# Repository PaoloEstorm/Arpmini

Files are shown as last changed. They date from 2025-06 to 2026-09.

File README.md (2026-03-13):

# ARPMINI

Arpmini is a powerful mini MIDI processor that offers advanced features such as an arpeggiator, note/drum sequencer, and editor. It’s designed to control external MIDI instruments for live performances or music production.

# ARPMINI REQUIRES [Arpmini-Core](https://github.com/PaoloEstorm/Arpmini-Core) TO WORK CORRECTLY!

## Give that dusty old synth in your closet a fresh new life! Unlock a ton of advanced features and unleash your creativity with Arpmini



## Its features include:

Simple and intuitive UI

MIDI Tracker and Piano Roll–style sequence editors

Four backlit buttons, mappable and controllable via MIDI CC

2 MIDI outputs and 2 MIDI inputs - using the MIDI-TRS standard

Integrated MIDI->USB / USB->MIDI interface, fully compatible with Mac, Windows, Linux, Android and iOS 

32KB of memory to store up to 60 songs and various global settings

Import/export songs between Arpmini and your computer using [Arpmini Editor](https://github.com/PaoloEstorm/Arpmini-Editor)

Built-in speaker for acoustic feedback and metronome and much much more!

## Arpmini Modes

Modes

Arp Mode: Arpeggiates the played notes based on the selected arpeggio style.

Rec Mode: Records and plays back up to 8 patterns of variable length, with a maximum of 32 notes each.

Song Mode: Allows to chain up 8 recorded patterns, in any desired order.

Live Mode: Allows the playback of one of the 8 different patterns, each assigned to one buttons/multi-button-combo.

Wiring

A simulated demo of Arpmini can be explored on Wokwi via the link https://wokwi.com/projects/430279970010982401

Simplified Schematic:

Schematic_DIY

# Build your own Arpmini by following the [Assembly Guide](https://github.com/PaoloEstorm/Arpmini/blob/main/BUILD_INSTRUCTIONS.md)!

## Schematic and PCB design [here](https://oshwlab.com/estorm/miniseq)

Enclosure 3D model [here](https://github.com/PaoloEstorm/Arpmini/blob/main/extras/Arpmini%201.65%20v3.stl)

Pro Micro: https://amzn.eu/d/if0r67j

Oled Display (blue): https://amzn.eu/d/c0RTBxJ or Oled Display (white): https://amzn.eu/d/1IbVAiL

Buttons: https://amzn.eu/d/7UyjFKx

Buzzer: https://amzn.eu/d/fEAc4UO

Screws: https://amzn.eu/d/e37jcLp

Brass inserts: https://amzn.eu/d/hlBMRaH

Pin Headers: https://amzn.eu/d/9up7Byu

3.5mm Stereo jacks: https://amzn.eu/d/9LeCoT1

External labels [here](https://github.com/PaoloEstorm/Arpmini/tree/main/extras)

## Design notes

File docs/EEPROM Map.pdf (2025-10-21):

System | 0 - MIDI Channel | 1 - Realtime | 2 - Sound Mode | 3 - Sync Port | 4 - Red CC | 5 - Yellow CC | 6 - Blue CC | 7 - Green CC | 8 – Empty | 9 – Empty | 10 – Empty | 11 – Empty | 12 – Empty | 13 – Empty | 14 – Empty | 15 – Check
| 16 –Empty | 17 – Empty | 18 – Empty | 19 – Empty | 20 – Empty | 21 – Empty | 22 – Empty | 23 – Empty | 24 – Empty | 25 – Empty | 26 – Empty | 27 – Empty | 28 – Empty | 29 – Empty | 30 – Empty | 31 – Empty
Song1 | 32 - Empty/Full | 33
| | Pitch-Mode+Swing | 34 – Pitch | 35 – Scale | 36– Post-Transpose | 37 - Seq. Length | 38 - BPM | 39 – Speed | 40 - Pattern 1 | 41 - Pattern 2 | 42 - Pattern 3 | 43 - Pattern 4 | 44 - Pattern 5 | 45 - Pattern 6 | 46 - Pattern 7 | 47 - Pattern 8
Sequence 1 | 48 | 49 | 50 | 51 | 52 | 53 | 54 | 55 | 56 | 57 | 58 | 59 | 60 | 61 | 62 | 63
| 64 | 65 | 66 | 67 | 68 | 69 | 70 | 71 | 72 | 73 | 74 | 75 | 76 | 77 | 78 | 79
Sequence 2 | 80 | 81 | 82 | 83 | 84 | 85 | 86 | 87 | 88 | 89 | 90 | 91 | 92 | 93 | 94 | 95
| 96 | 97 | 98 | 99 | 100 | 101 | 102 | 103 | 104 | 105 | 106 | 107 | 108 | 109 | 110 | 111
Sequence 3 | 112 | 113 | 114 | 115 | 116 | 117 | 118 | 119 | 120 | 121 | 122 | 123 | 124 | 125 | 126 | 127
| 128 | 129 | 130 | 131 | 132 | 133 | 134 | 135 | 136 | 137 | 138 | 139 | 140 | 141 | 142 | 143
Sequence 4 | 144 | 145 | 146 | 147 | 148 | 149 | 150 | 151 | 152 | 153 | 154 | 155 | 156 | 157 | 158 | 159
| 160 | 161 | 162 | 163 | 164 | 165 | 166 | 167 | 168 | 169 | 170 | 171 | 172 | 173 | 174 | 175
Sequence 5 | 176 | 177 | 178 | 179 | 180 | 181 | 182 | 183 | 184 | 185 | 186 | 187 | 188 | 189 | 190 | 191
| 192 | 193 | 194 | 195 | 196 | 197 | 198 | 199 | 200 | 201 | 202 | 203 | 204 | 205 | 206 | 207
Sequence 6 | 208 | 209 | 210 | 211 | 212 | 213 | 214 | 215 | 216 | 217 | 218 | 219 | 220 | 221 | 222 | 223
| 224 | 225 | 226 | 227 | 228 | 229 | 230 | 231 | 232 | 233 | 234 | 235 | 236 | 237 | 238 | 239
Sequence 7 | 240 | 241 | 242 | 243 | 244 | 245 | 246 | 247 | 248 | 249 | 250 | 251 | 252 | 253 | 254 | 255
| 256 | 257 | 258 | 259 | 260 | 261 | 262 | 263 | 264 | 265 | 266 | 267 | 268 | 269 | 270 | 271
Sequence 8 | 272 | 273 | 274 | 275 | 276 | 277 | 278 | 279 | 280 | 281 | 282 | 283 | 284 | 285 | 286 | 287
| 288 | 289 | 290 | 291 | 292 | 293 | 294 | 295 | 296 | 297 | 298 | 299 | 300 | 301 | 302 | 303

Drum notes /
Shifts | 304 | 305 | 306 | 307 | 308 | 309 | 310 | 311 | 312 – Empty | 313 - Empty | 314 – Empty | 315 – Empty | 316 – Empty | 317 – Empty | 318 – Empty | 319 – Empty
Song2 | 320 | … | … | … | … | … | … | … | … | … | … | … | … | … | … | …

# EEPROM MAP (EXTERNAL)

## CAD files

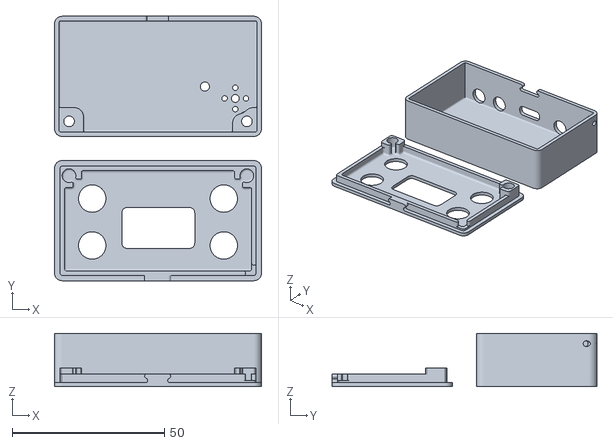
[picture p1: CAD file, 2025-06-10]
extras/Arpmini 1.65 v3.stl
68.0 x 86.9 x 17.5

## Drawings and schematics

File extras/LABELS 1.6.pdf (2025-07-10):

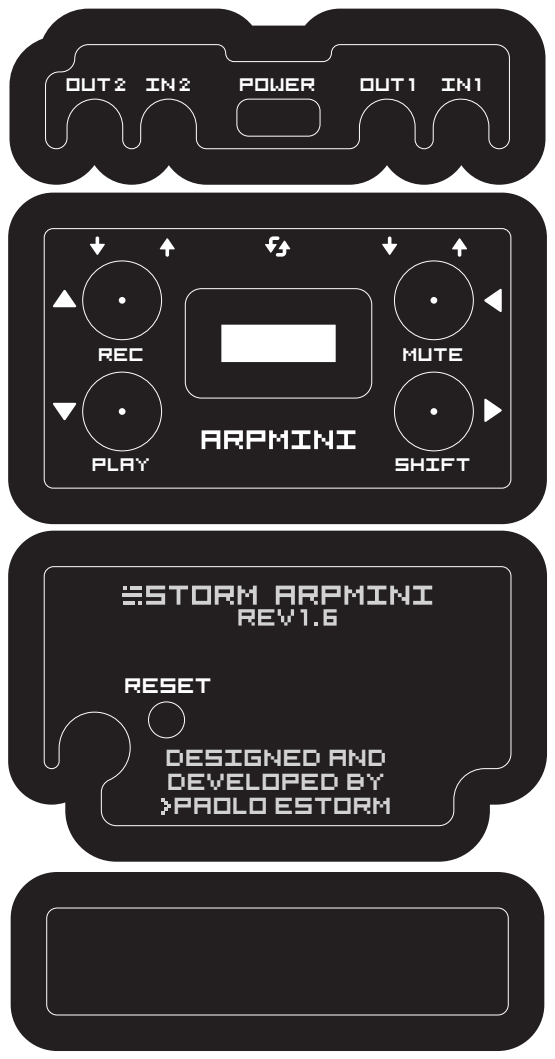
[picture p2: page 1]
OUT 2; POWER; OUT 1; DESIGNED AND DEVELOPED BY PAOLO ESTORM; RESET; REC; PLAY; MUTE; SHIFT

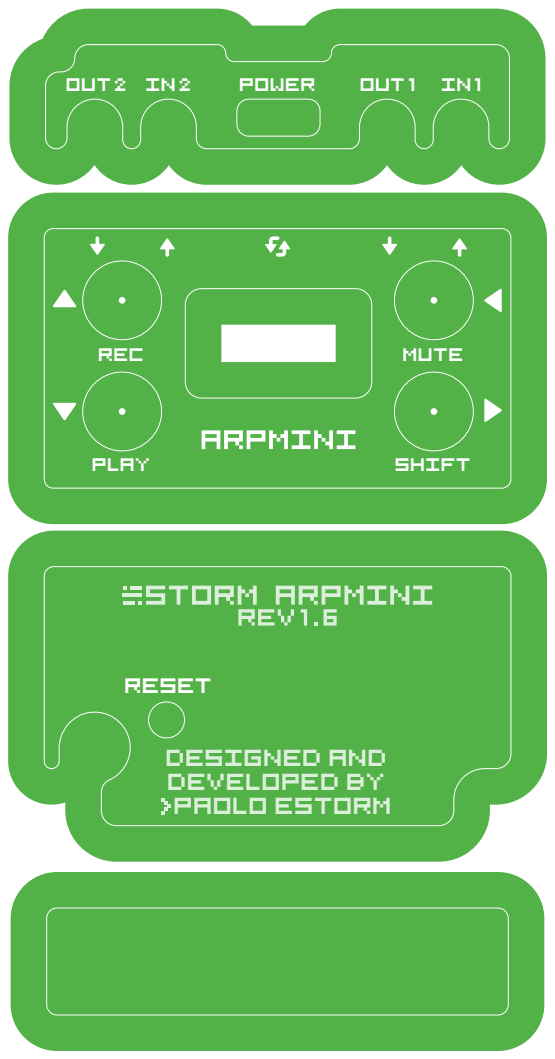
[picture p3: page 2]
OUT 2; POWER; OUT 1; DESIGNED AND DEVELOPED BY PAOLO ESTORM; RESET; REC; PLAY; MUTE; SHIFT

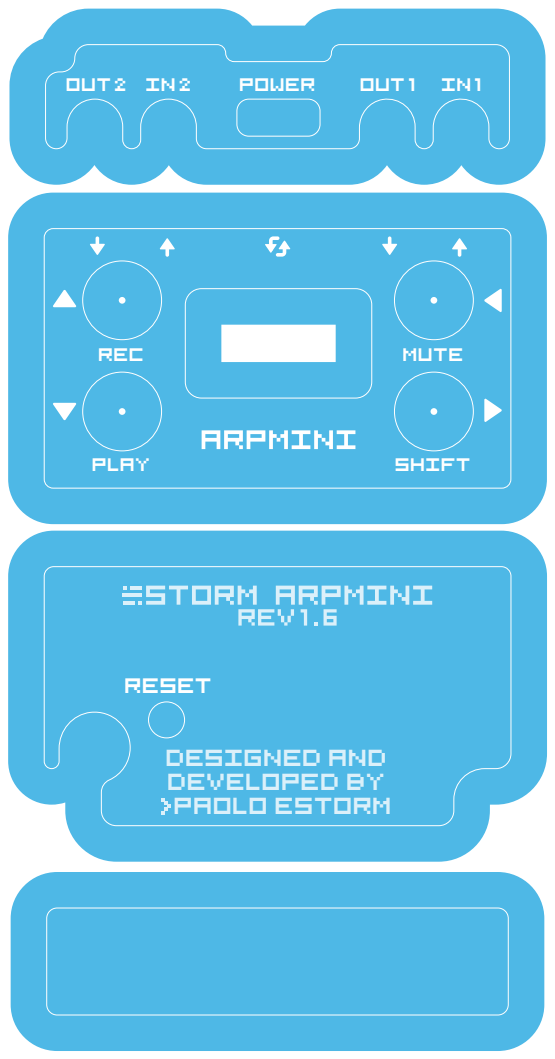
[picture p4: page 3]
OUT 2; POWER; OUT 1; DESIGNED AND DEVELOPED BY PAOLO ESTORM; RESET; REC; PLAY; MUTE; SHIFT

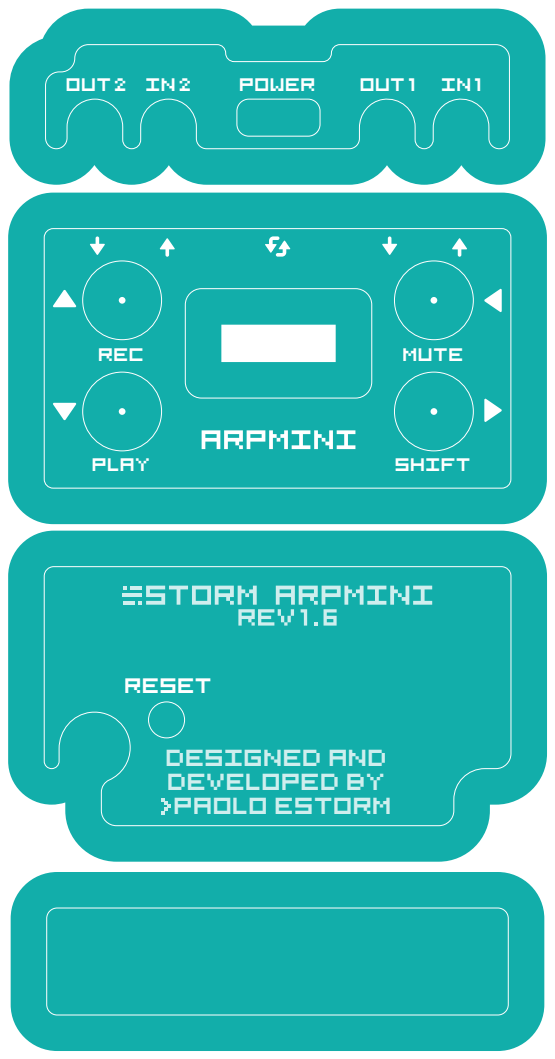
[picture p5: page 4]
OUT 2; POWER; OUT 1; DESIGNED AND DEVELOPED BY PAOLO ESTORM; RESET; REC; PLAY; MUTE; SHIFT

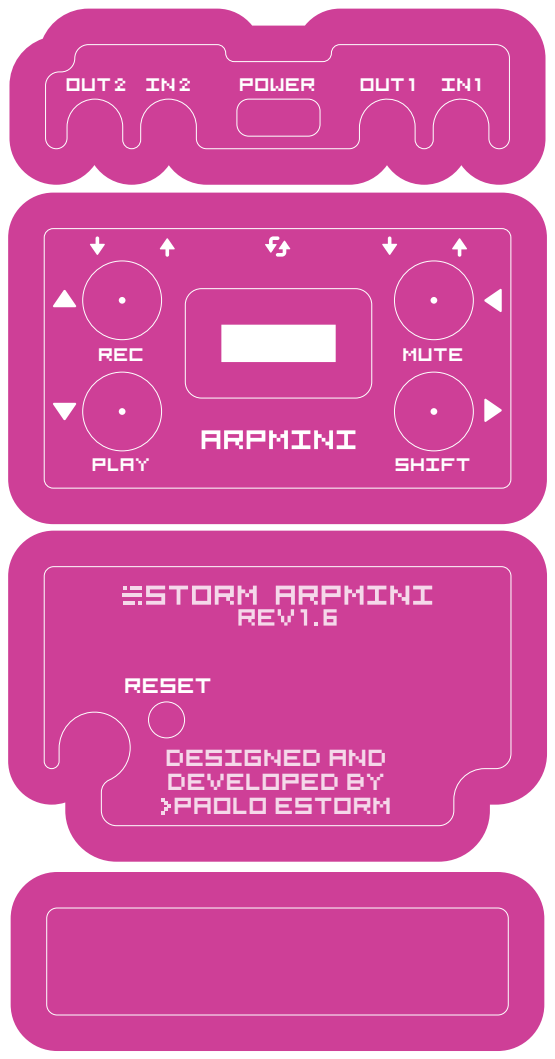
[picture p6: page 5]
OUT 2; POWER; OUT 1; DESIGNED AND DEVELOPED BY PAOLO ESTORM; RESET; REC; PLAY; MUTE; SHIFT

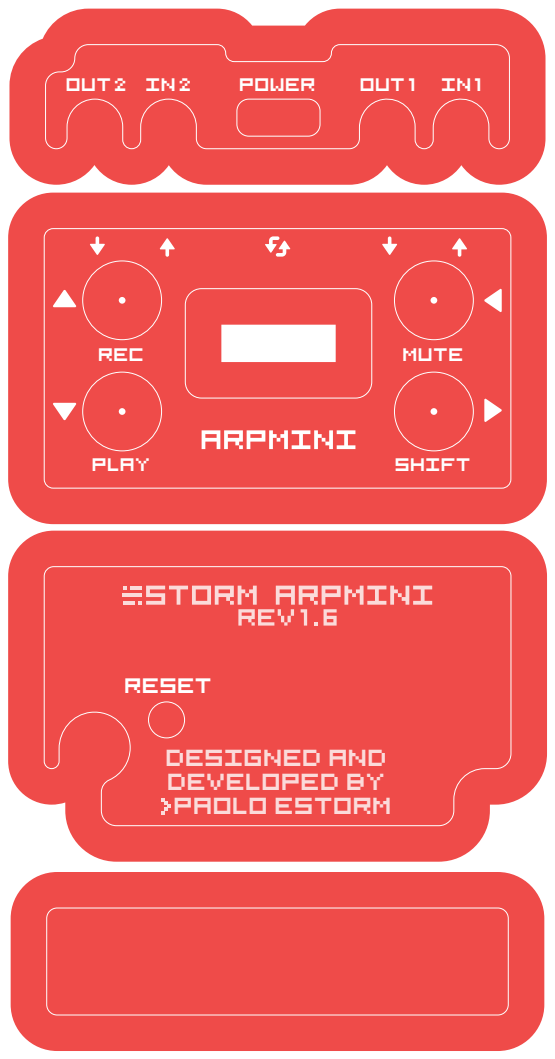
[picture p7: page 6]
OUT 2; POWER; OUT 1; DESIGNED AND DEVELOPED BY PAOLO ESTORM; RESET; REC; PLAY; MUTE; SHIFT

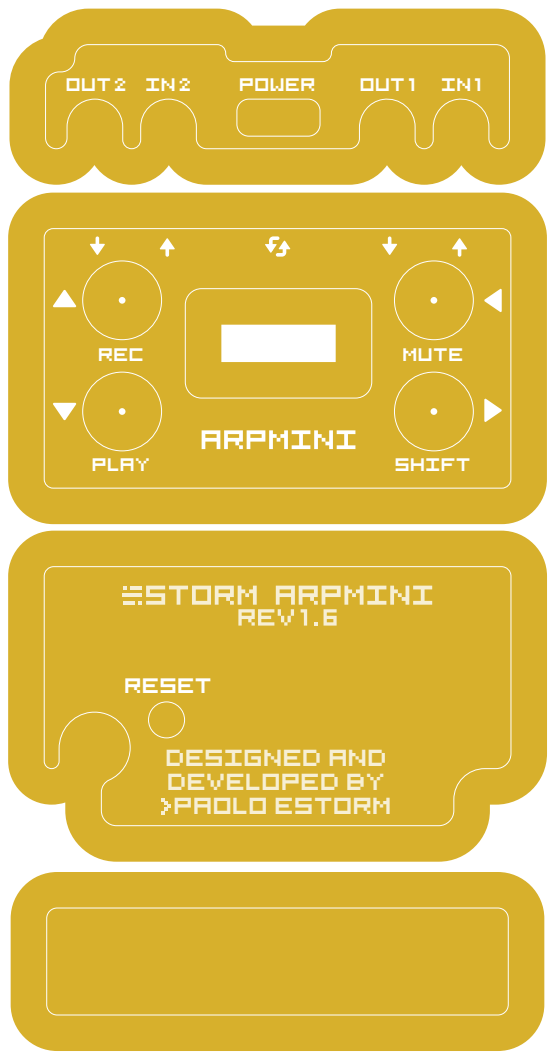
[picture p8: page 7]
OUT 2; POWER; OUT 1; DESIGNED AND DEVELOPED BY PAOLO ESTORM; RESET; REC; PLAY; MUTE; SHIFT

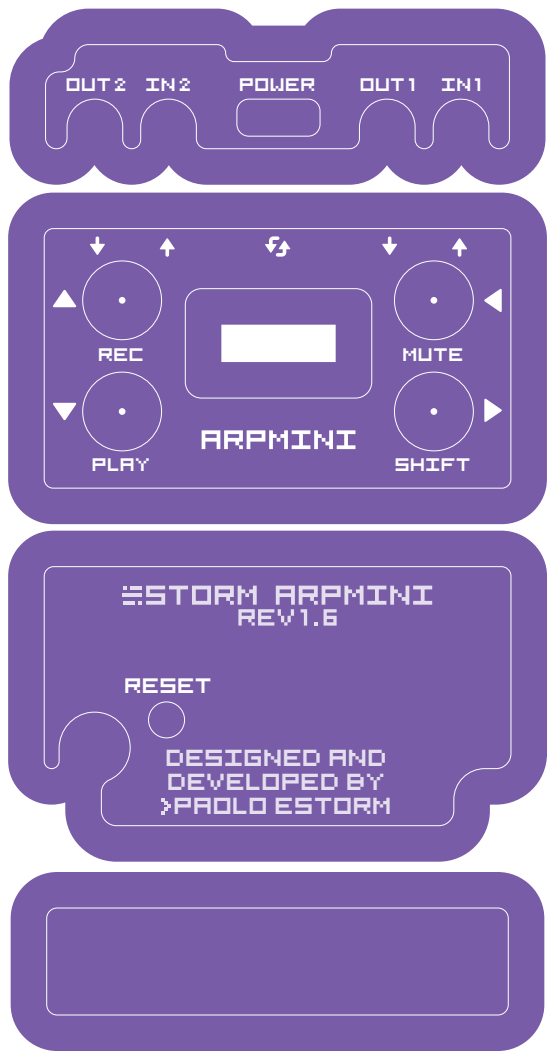
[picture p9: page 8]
OUT 2; POWER; OUT 1; DESIGNED AND DEVELOPED BY PAOLO ESTORM; RESET; REC; PLAY; MUTE; SHIFT

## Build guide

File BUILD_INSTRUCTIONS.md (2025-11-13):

# Arpmini Assembly Guide



Required components: 
- 1x Pro Micro: https://amzn.eu/d/if0r67j
- 1x Arpmini PCBs: https://oshwlab.com/estorm/miniseq
- 1x 0,96" SPI Oled Display (Blue): https://amzn.eu/d/c0RTBxJ or (White): https://amzn.eu/d/1IbVAiL
- 4x Button+LED, (1x Red, 1x Yellow, 1x Green, 1x Blue): https://amzn.eu/d/7UyjFKx
- 1x 9x5.5mm Buzzer: https://amzn.eu/d/fEAc4UO
- 2x M3-14mm Screws: https://amzn.eu/d/e37jcLp
- 2x Brass Inserts: https://amzn.eu/d/hlBMRaH
- 4x 3.5mm Stereo Jacks: https://amzn.eu/d/9LeCoT1
- 1x Single Row Male Pin Header Strip: https://amzn.eu/d/9up7Byu
- 1x 3D Printed Enclosure: https://github.com/PaoloEstorm/Arpmini/blob/main/extras/Arpmini%201.65%20v3.stl
- Optional, External Labels: https://github.com/PaoloEstorm/Arpmini/tree/main/extras

## Some parts will no longer be easily accessible after assembly, so make sure you have everything you need before starting, and follow the steps in the exact order.




Insert the four 3.5 mm jack sockets into their corresponding holes, making sure to mount them on the correct side of the PCB; the one with the logo and SMD components.



While keeping the sockets in place, solder each exposed pin one by one, making sure the connectors stay as straight, flat, and aligned with the PCB as possible.
You can use a strip of adhesive tape to hold them steady during the process if needed.



Using a flush side cutter, trim the excess length of the soldered pins as much as possible.
Be careful not to damage the PCB traces; a clean trim helps prevent short circuits in later assembly steps.



Take the Pro Micro board and make sure you have the male pin headers ready.
They usually come included with the board. If not, cut two 12-pin strips from a longer header.



Most Pro Micro boards include two small pads located next to the TX pin. These pads define the board’s operating voltage:
if the pads are not bridged, the board runs at 3.3V;
if they are bridged, the board runs at 5V.



Arpmini operates at 5V, so the pads MUST be bridged using a small amount of solder.
Be careful not to damage nearby components. A fine-tip soldering iron and moderate temperature (around 280°C / 536°F) make the process easy.



Insert the two 12-pin male headers into the holes, making sure to place them on the side of the PCB with the "Pro Micro" label and the microcontroller.
Flip the board and solder all pins, aiming for clean joints without using too much solder, while keeping the headers pressed firmly against the board.
Using a breadboard to hold the pins in place during soldering can be very helpful!



Once the headers are soldered, proceed to flash the bootloader specifically designed for Arpmini.
To connect the board to the ISP, it is recommended to use Dupont jumper cables to avoid soldering.

Alternatively, you can temporarily solder wires on the back side of the board, where the headers were just soldered, while keeping the front headers untouched.

Bootloader_ProMicro_Wiring

Follow the instructions available [here](https://github.com/PaoloEstorm/Arpmini-Core) to install the Arpmini Core in the Arduino IDE.
Once installed, go to Tools -> Board -> Arpmini Core -> Arpmini.
Then, in Tools -> Programmer, select Arduino as ISP.
In Tools -> Port, select the serial port of your Arduino Uno/Nano/ISP.
Finally, click Burn Bootloader in the Tools menu.
If the connections and configuration are correct, the bootloader should be successfully written within a few seconds.




Place the Pro Micro board face down, inserting it into the holes of the main PCB as shown in the photo.



Double-check the placement before soldering!
Solder all pins, keeping the PCBs pressed firmly and aligned with each other.

Optionally, you can perform a continuity test between the front and back solder joints of each pin; if the soldering is done correctly, this step should not be necessary.



Using the flush side cutter, trim the excess length of the soldered pins as much as possible.

Be careful not to damage the PCB traces; a clean trim helps prevent short circuits in later assembly steps.





Place the buzzer on the top side of the main PCB, observing the correct polarity.
The hole marked (+) on the PCB must align with the (+) on the buzzer.

Double-check the placement before soldering.





Using the flush side cutter, trim the excess length of the soldered pins as much as possible.

Be careful not to damage the PCB traces; a clean trim helps prevent short circuits in later assembly steps.



Now start assembling the screen board.
Insert the buttons into their respective slots, matching the colors marked on the PCB.
Pay special attention to the pin marked in red — this is GND and must be inserted towards the inside of the board.
For all buttons, the red-marked pins should face each other and point inward on the PCB.

To make inserting the pins easier, especially the thin ones for the LEDs, using tweezers can be helpful.




Before soldering, double-check that all buttons are correctly positioned.




Using the flush side cutter, trim the excess length of the soldered pins as much as possible.

Be careful not to damage the PCB traces; a clean trim helps prevent short circuits in later assembly steps.




Using a flush side cutter, cut out two individual male pin headers.



Place the individual headers into the two holes at the bottom of the PCB, near the yellow and green buttons.



Then, position the screen on top of the headers and into the holes at the top of the PCB.
Screens usually come with pre-soldered pin headers; if not, cut a 7-pin strip and solder it to the screen PCB as shown in the photo above.

Be careful not to damage any PCB traces.
I recommend to keep the protective film on the screen to shield it from potential solder flux splashes.



Flip the board and solder all pins, aiming for clean joints without using too much solder, while keeping the headers pressed firmly against the board.



Flip the PCB to the button side and solder the two support pins of the screen.



Using the flush side cutter, trim the excess length of the soldered pins as much as possible.

Be careful not to damage the PCB traces; a clean trim helps prevent short circuits in later assembly steps.



Flip the board to the button side and trim the excess length of both the 7-pin header on the screen and the two individual support headers as well.



Cut off four 4-pin strips from a male header.




Flip the main board to the side marked "screen board goes here" and place the four header strips: two on the left and right sides, and two on the bottom side, as shown in the photo above.



Keeping the main board in the same position (with "screen board goes here" facing up), sandwich the previously assembled screen board on top.
Double-check that it is correctly positioned.



Solder all the headers on both sides while keeping the two boards pressed firmly together.



Solder all the headers on both sides while keeping the two boards pressed firmly together.



Using the flush side cutter, trim the excess length of the soldered pins as much as possible.

Be careful not to damage the PCB traces; a clean trim ensures the enclosure will close properly.



On the main board, trim the excess length of the Pro Micro’s pin headers as well.

Be careful not to damage the PCB traces or any nearby components; a clean trim ensures the enclosure will close properly.



The internal assembly is complete!



After making sure the two boards are properly aligned and parallel to each other, you can proceed to flash the firmware.

Connect Arpmini to your computer using a USB-C cable.
A red LED between the main board and the Pro Micro should light up, indicating that the bootloader is ready to receive the firmware.

Download the full [Arpmini](https://github.com/PaoloEstorm/Arpmini) project and open the Arpmini.ino file with the Arduino IDE.

Make sure Arpmini is selected under Tools -> Board -> Arpmini Core -> Arpmini, then click Upload.

During the upload, press the yellow and blue buttons on Arpmini simultaneously to start the EEPROM initialization procedure.

If you miss the timing, you can still initialize the EEPROM by unplugging and reconnecting Arpmini while holding both buttons.

For this first upload, selecting the serial port is not necessary/possible, but for future uploads you will need to choose Arpmini from the list of available serial ports.




After installing the firmware, check that the screen works properly, each button lights up when pressed, and the buzzer produces sound.
If everything functions correctly, Arpmini is ready! Otherwise, inspect the solder joints connecting the two boards to identify any potential issues.



Now proceed with assembling the 3D-printed case using the [model](https://github.com/PaoloEstorm/Arpmini/blob/main/extras/Arpmini%201.65%20v3.stl) provided in the main project.



Rest the brass inserts into the dedicated slots on the inner side of the front panel, without pressing them in yet.




Using a hot soldering iron tip, gently heat the brass insert while applying light pressure.
The insert will begin to sink in once it reaches the temperature needed to melt the plastic (PLA in this case).
Avoid pressing too hard if it doesn’t go in; instead, slightly increase the soldering iron temperature if possible.




The inserts should sit flush with their slots or be slightly recessed.
Avoid heating them for too long, as excessive heat may deform the surrounding plastic.




Now place the PCB into the bottom case, tilting it slightly forward to help align the case openings with the ports.
Once aligned, apply gentle downward pressure to fit it in place.



Now it’s time to remove the protective film from the screen!



Now, tilt the top cover with the inserts slightly forward and close the enclosure.
If the inserts were properly installed, the closure should be gapless.



Flip the assembly face down and screw in two of the M3 screws (14mm long) into the designated holes.



Arpmini assembly is now complete!
In the next step, I will apply the labels, but this is optional and purely for aesthetic purposes.








by Paolo Estorm <3

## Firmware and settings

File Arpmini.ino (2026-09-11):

/*!
 *  @file       Arpmini.ino
 *  Project     Estorm - Arpmini
 *  @brief      MIDI Sequencer & Arpeggiator
 *  @version    2.37
 *  @author     Paolo Estorm
 *  @date       2026/07/30
 *  @license    GPL v3.0 
 *
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
 *  You should have received a copy of the GNU General Public License
 *  along with this program.  If not, see <http://www.gnu.org/licenses/>.
 */

// Inspired by the "arduino based midi sequencer" project by Brendan Clarke
// https://brendanclarke.com/wp/2014/04/23/arduino-based-midi-sequencer/

// system
const char version[] PROGMEM = "V2.37";
#include "Vocabulary.h"
#include "Random8.h"
Random8 Random;
#define bitToggle8(value, bit) ((value) ^= (1 << (bit)))  // flip bit (8 bit version)
#define bitSet8(value, bit) ((value) |= (1 << (bit)))     // set bit high (8 bit version)
#include <avr/wdt.h>

// LEDs
#define redLED 0
#define yellowLED 1
#define blueLED 2
#define greenLED 3

volatile uint8_t* const ledPort[4] = { &PORTD, &PORTD, &PORTC, &PORTD };  // red, yellow, blue, green
const uint8_t ledBit[4] = { _BV(PD0), _BV(PD1), _BV(PC6), _BV(PD4) };     // matching bits

// sound
uint8_t soundmode = 1;      // 1 audio on, 2 ui sounds off, 3 off
bool metro = false;         // metronome toggle
bool confirmsound = false;  // at button press, play the confirmation sound instead of the click
#include "Tone8.h"
Tone8 tone8;

// screen
#include "SPI_OLED.h"
SPI_OLED oled;                   // screen initialization
bool StartScreenTimer = true;    // activate the screen-on timer
bool alertnotification = false;  // keep track of notifications, timeout timer
uint8_t safeNotification = 0;    // print notification from timer interrupt without glitches

// memory
#define memorySlots 60   // max number of songs (max 99) (absolute max is 110 but with graphical glitches)
#include "I2C_EEPROM.h"  // external 32kb eeprom
I2C_EEPROM EEPROM2;

// midi
#include "MIDIUSB.h"
#include <MIDI.h>
#include "SoftwareSerial_MiniRX.h"
SoftwareSerial Serial2(10);                            // midi2 pin (input)
MIDI_CREATE_INSTANCE(HardwareSerial, Serial1, MIDI);   // initialize midi1
MIDI_CREATE_INSTANCE(SoftwareSerial, Serial2, MIDI2);  // initialize midi2
uint8_t midiChannel = 1;                               // MIDI channel to use for sequencer 1 to 16
int8_t syncport = 1;                                   // activate midi-in sync 0=off, 1=port1, 2=port2, 3=usb

// buttons
#define yellowbutton 6  // yellow button pin
#define redbutton 7     // red button pin
#define greenbutton 8   // green button pin
#define bluebutton 9    // blue button pin

bool EnableButtons = true;  // if controlled externally (by CC) disable all buttons
uint8_t greentristate = 1;  // 0=off, 1=null, 2=on
bool redstate = false;      // is redbutton pressed?
bool yellowstate = false;   // is yellowbutton pressed?
bool greenstate = false;    // is greenbutton pressed?
bool bluestate = false;     // is bluebutton pressed?

uint8_t buttonCC[4];             // midi CC value for each button
int8_t numbuttonspressedCC = 0;  // number of externally pressed buttons
uint8_t mapButtonSelect = 0;     // 0=red, 1=yellow, 2=blue, 3=green

// menu
const uint8_t NUM_MENUITEMS = 21 - 1;  // number of menu items

uint8_t menuitem = 2;        // the current menu item
uint8_t menunumber = 0;      // 0=mainscreen, 1=menu, 2=submenu, 3=file manager, 4=popups, 5=editor, 6=notifications
uint8_t savemode = 0;        // 0=bake, 1=clone, 2=new, 3=save, 4=load, 5=delete
uint8_t savecurX = 0;        // cursor position in file manager, 0-5
uint8_t savepage = 0;        // page number for external eeprom
bool confirmation = false;   // confirmation popup inside file manager
bool full = false;           // is the selected save slot full?
int8_t curpos = 0;           // cursor position in songmode, 0-7
bool StartMenuTimer = true;  // activate the go-to-menu timer
uint8_t Jittercur = 0;       // cursor position in the jitter submenu
bool cloneCur = false;       // cursor position in the clone seq submenu
bool editorPopup = false;    // normal popup or in editor popup?
bool selectORclear = false;  // seq select popup  // clear current seq or seq select popup? false = select, true = clear
uint8_t currentSeqEdit = 0;  // sequence that you are editing in editor
uint8_t colum;               // vertical position in editor
uint8_t row;                 // orizontal position in editor
uint8_t frame;               // vertical page/section in editor
uint8_t window;              // orizontal page/section in editor
uint8_t sidemenuitem = 1;    // selected item in the note editor's side-menu (0=transp. octave, 1=transp. note, 2=shift sequence)

// time keeping
bool playing = false;               // is the sequencer playing?
uint8_t clockTimeout;               // variable for keeping track of external/internal clock
bool internalClock = true;          // is the sequencer using the internal clock?
uint8_t StepSpeed = 3;              // 0=1/48, 1=1/32, 2=1/24, 3=1/16, 4=1/12, 5=1/8, 6=1/6, 7=1/4
bool FixSync = false;               // re-allign the sequence when changing step-speeds
uint8_t sendrealtime = 1;           // send midi realtime messages. 0=off, 1=on (@internalclock, only if playing), 2=on (@internalclock, always)
uint8_t tSignature = 4;             // time signature for LED indicator/metronome and beats, 1 - 8 (1*/4, 2*/4..to 8/4)
int8_t countBeat;                   // keep track of the time beats
int8_t countStep;                   // keep track of note steps in seq/song mode
int8_t IntercountStep;              // keep track of note steps while inter-recording
volatile bool stepEnable = false;   // keep track of internal timer ticks
int8_t countTicks;                  // clock ticks counter for notes timing
int8_t globalTicks;                 // clock ticks counter for global timing & reference
uint8_t ticksPerStep = 6;           // how many clock ticks (countTicks) before the sequencer moves to the next step
uint8_t flip = 6;                   // part of the frameperstep's flipflop
uint8_t flop = 6;                   // part of the frameperstep's flipflop
bool flipflopEnable;                // switch for the frameperstep's flipflop
bool swing = false;                 // is swing enabled?
bool snapmode = 0;                  // when play/stop the next sequence in live mode. 0=pattern, 1=beat
bool start = false;                 // dirty fix for a ableton live 10 bug. becomes true once at sequence start and send a sync command
bool armStart = false;              // count-in: armed one beat before the recording downbeat, sends Start just before its clock
uint8_t BPM = 120;                  // beats per minute for internalclock - min 20, max 250 bpm
const uint8_t TAP_ITERATIONS = 8;   // how many BPM "samples" to averege out for the tap tempo. more = more accurate
uint8_t BPMbuffer[TAP_ITERATIONS];  // BPM "samples" buffer for tap tempo

// arpeggiator
const uint8_t MAX_ARPNOTES = 10;    // maximum number of notes that can be arpeggiated
uint8_t activeNotes[MAX_ARPNOTES];  // contains the MIDI notes the arpeggiator plays
bool ArpDirection;                  // alternate up-down for arpstyle 2, 3, 4 & 5
uint8_t arpstyle = 0;               // 0=up, 1=down, 2=up-down, 3=down-up, 4=up+down, 5=down+up, 6=random
uint8_t arpcount;                   // number of times the arpeggio repeats
uint8_t arprepeat = 1;              // number of times the arpeggios gets trasposed by "stepdistance"
int8_t stepdistance = 12;           // distance in semitones between each arp repeat, -12 to +12
int8_t numNotesHeld = 0;            // how many notes are currently pressed on the keyboard
uint8_t numActiveNotes = 0;         // number of notes currently stored in the activeNotes array
uint8_t trigMode = 0;               // 0=hold, 1=trigger, 2=retrigged
bool strum = false;                 // strum mode enabled?

// sequencer
bool recording = false;                         // is the sequencer in the recording state?
bool countIN_Enable = true;                     // start recording after a countdown?
bool trig_countIN = false;                      // trigger the count-in
uint8_t countIN_Count = 0;                      // keep track of the count-in count
bool keybTransp = true;                         // enable transpose by key? (only rec, song & live mode)
const uint8_t KEYB_BASENOTE = 48;               // for transpose by key, the sequence is transposed based on the note C3 (midi note 48)
uint8_t keybTransposeNote = 48;                 // the last note number received for transposing the sequence
uint8_t seqLength = 16;                         // the number of steps the sequence is looped for
uint8_t NewSeqLength = 16;                      // 1-32 seq.length of the newly created song
uint8_t currentSeq = 0;                         // the currently selected sequence. 0-7
uint8_t newcurrentSeq = 0;                      // the next sequence is going to play in live mode. 0-7
uint8_t currentSeqDestination = 0;              // destination sequence for the cloning function
uint8_t currentSeqSource = 0;                   // source sequence for the cloning function
const uint8_t MAX_SEQLENGTH = 32;               // the maximum possible number of steps
const uint8_t NUM_SEQUENCES = 8;                // the number of total sequences
uint8_t noteSeq[NUM_SEQUENCES][MAX_SEQLENGTH];  // sequences arrays
const uint8_t NUM_PATTERNS = 8;                 // number of patterns
uint8_t songPattern[NUM_PATTERNS];              // pattern array
int8_t pattern = 0;                             // currently playing pattern
bool chainrec = false;                          // sequential recording in song mode?
bool lockpattern = false;                       // block the current pattern from sequencing
bool nopattern = false;                         // inhibit current pattern from sequencing only once
bool updatePatternCursor = false;               // update pattern cursor avoiding indirect recursive call

// notes
int8_t pitch = 0;                 // pitch transposition: -12 to +12
bool pitchmode = false;           // 0=before scale, 1=scale root
uint8_t scale = 0;                // 0=linear, 1=penta.major, 2=penta.minor, 3=major, 4=minor, 5=harmonic minor, 6=locrian, 7=lydian, 8=dorian, 9=phrygian, 10=inverted, 11=hexatonal
int8_t posttranspose = 0;         // post-scale pitch transposition: -12 to +12
uint8_t noteLengthSelect = 3;     // set the notelength, 0=random, 1=10%, 2=30%, 3=50%, 4=70%, 5=90%, 6=110%
bool longRandomLength = true;     // allow the longest (110%) length when random notelength is selected
bool sortnotes = true;            // sort the ActiveNotes array?
bool muted = false;               // suspend playing any notes from the sequencer (global)
bool lockmute = false;            // keep muted. only in arp, seq & song mode
bool suspended = false;           // temporarily suspend playing any notes from the sequencer (only rec & live mode)
bool scheduleSuspend = false;     // toggle the "suspended" state in sync according to the snapmode, in live mode
bool enableSustain = true;        // enable sustain pedal functionalities
bool sustain = false;             // hold notes also if trigmode > 0
const uint8_t QUEUE_LENGTH = 8;   // the number of notes that can overlap if notelength is 120%
int8_t cronNote[QUEUE_LENGTH];    // stores the notes playing
int8_t cronLength[QUEUE_LENGTH];  // stores the amount of time a note has left to play
uint8_t jitrange = 0;             // jitter range 0-24
uint8_t jitprob = 0;              // jitter probability 0-10 (0-100%)
uint8_t jitmiss = 0;              // probability of a note to be not played (0-90%)
uint8_t shiftSeq[NUM_SEQUENCES];  // keep track of how much each sequence has been shifted

// drum mode
bool drumMode = false;             // is drum mode enabled?
bool drumModeSelect = false;       // pre-selection for drum mode
const uint8_t DRUM_SLOTS = 8;      // number of drum slots available. must be 8 (8bit) do not change!
uint8_t DrumNotes[DRUM_SLOTS];     // midi notes associated to each drum slot
bool ActiveDrumNotes[DRUM_SLOTS];  // keep track of the currently pressed midi drum notes
bool DrumNotesMixer[DRUM_SLOTS];   // enable/disable drum slot
bool drumroll = false;             // repeat note while key is pressed?
uint8_t drumKeybMode = 1;          // 0=free, 1=sync, 2=roll, 3=mixer

// general
uint8_t modeselect = 0;     // 0=arp.mode, 1=rec.mode, 2=song mode, 3=live mode
uint8_t premodeselect = 0;  // pre-selection of the mode in submenu

void BootAnimation() {  // play the boot animation

  oled.setSize(3);  // set font size to 3x

  for (uint8_t i = 0; i <= 22; i++) {  // scroll "arpmini"
    oled.setCursorXY(2, i);
    oled.println(F("ARPMINI"));
    delayMicroseconds(12500);
  }

  oled.setCursorXY(10, 0);
  oled.print(F(":STORM"));

  oled.setSize(2);
  oled.setCursorXY(34, 48);
  oled.printF(version);

  Bip(2);  // startup Sound
}
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
void loop() {  // run repeatedly

  TCTask();   // read incoming MIDI data
  TCTask2();  // check if is time to run the internal clock

  if (Serial.available()) {  // if incoming serial data from USB
    PcSync(Serial.read());   // read incoming serial data
  }

  DebounceButtons();   // debounce buttons
  ScreenOnTimer();     // check if is time to dim or turn OFF the display
  GoToMenuTimer();     // main screen, check if green button is pressed for long enough to enter the menu
  PrintLiveObjects();  // update main screen objects
}

void ResetEEPROM() {  // initialize the EEPROM with default values

  oled.printlnF(printcleaning);

  for (uint8_t i = 0; i < memorySlots; i++) {

    if (i < 4) {
      EEPROM2.update(i, 1);           // midiChannel, sendrealtime, soundmode, syncport
      EEPROM2.update(4 + i, i + 30);  // buttons cc
    }

    for (uint16_t j = 0; j < 288; j++) {
      EEPROM2.update(eepromaddress(32 + j, i), 0);  // clean songs slots
    }

    oled.printF(minus);                     // print progress bar
    if ((i + 1) % 20 == 0) oled.println();  // go to the next line after 20 "-"
  }

  EEPROM2.update(15, 65);  // set check byte
  tone8.tone(880, 250);
  oled.printF(printdone);
  delay(1000);
  oled.clear();
}

uint16_t eepromaddress(uint16_t address, uint8_t slot) {  // calculate eeprom song addresses

  const uint16_t SLOTSIZE = (NUM_SEQUENCES * MAX_SEQLENGTH) + 16 + 16;
  return (SLOTSIZE * slot) + address;
}

void PcSync(uint8_t data) {  // exchange data with PC (Arpmini Editor)

  static uint8_t enable = 0;  // 0=none, 1=command recieved , 2=song address recieved
  static uint8_t mode = 0;
  static uint8_t slot = 0;
  bool stop = false;
  static uint16_t writeIndex = 32;
  const uint16_t SLOT_OFFSET = 320 - 1;  // 32 bytes system + 288 song data -1

  // recieved commands
  const uint8_t CMD_CHECK_SLOT = 0xfc;
  const uint8_t CMD_READ_SLOT = 0xfd;
  const uint8_t CMD_WRITE_SLOT = 0xfe;
  const uint8_t CMD_STOP = 0xff;

  if (enable == 0) {  // select mode
    if (data >= CMD_CHECK_SLOT && data < CMD_STOP) {
      enable = 1;
      mode = data;
      return;
    } else stop = true;
  }

  else if (enable == 1) {  // select slot
    if (data > 0 && data <= memorySlots) {
      slot = data;
      enable = 2;
      return;
    } else stop = true;
  }

  else if (enable == 2) {  // check/read/write

    if (mode == CMD_CHECK_SLOT) {  // check slot
      Serial.write(EEPROM2.read(eepromaddress(32, slot - 1)));
      Serial.write(CMD_CHECK_SLOT);  // check confirmation
      enable = false;
    }

    else if (mode == CMD_READ_SLOT) {  // read entire slot
      for (uint16_t i = 32; i <= SLOT_OFFSET; i++) {
        uint8_t _data = EEPROM2.read(eepromaddress(i, slot - 1));
        if (_data != 0xff) Serial.write(_data);
        else Serial.write((uint8_t)0x00);
      }
      Serial.write(CMD_STOP);  // read confirmation
      enable = false;
    }

    else if (mode == CMD_WRITE_SLOT) {  // write
      if (data != 0xff) {
        EEPROM2.update((eepromaddress(writeIndex, slot - 1)), data);
        Serial.write(CMD_WRITE_SLOT);  // write confirmation
        if (writeIndex < SLOT_OFFSET) writeIndex++;
        else stop = true;
      } else stop = true;
    }
  }

  if (stop) {  // stop and reset
    stop = false;
    enable = false;
    mode = 0;
    slot = 0;
    writeIndex = 32;
    Serial.write(CMD_STOP);                            // stop confirmation
    if (menunumber == 3) PrintLoadSaveMenu(savemode);  // update screen
  }
}

void AllLedsOn() {  // turn ON all LEDs

  for (uint8_t i = 0; i <= 3; i++) {
    safedigitalWrite(i, HIGH);
  }
}

void AllLedsOff() {  // turn OFF all LEDs

  for (uint8_t i = 0; i <= 3; i++) {
    safedigitalWrite(i, LOW);
  }
}

void GoToMenuTimer() {  // greenbutton longpress, enter the menu

  static unsigned long SampleMenuTime;  // time in ms at which the timer was set
  static bool MenuTimerState;           // is the timer still running?

  if (StartMenuTimer) {  // start the timer
    StartMenuTimer = false;
    MenuTimerState = true;
    SampleMenuTime = millis();
  }

  if (MenuTimerState) {
    if (greentristate == 2) {                  // if green button is pressed
      if (millis() - SampleMenuTime > 1000) {  // if 1 second is passed
        MenuTimerState = false;
        greentristate = 1;
        if (recording) {  // disable recording
          recording = false;
          ManageRecording();
        }
        if (modeselect == 3) menuitem = 2;
        PrintMenu(menuitem);  // enter the menu
        Bip(2);               // confirmation sound
      }
    }
  }
}

void AlertTimeout() {  // automatically turn OFF notifications

  static unsigned long SampleAlertTime;  // time in ms at which the timer was set
  static bool AlertTimerState;           // is the timer still running?

  if (alertnotification) {  // start the timer
    alertnotification = false;
    AlertTimerState = true;
    SampleAlertTime = millis();
  }

  if (AlertTimerState) {
    if (millis() - SampleAlertTime > 1000) {
      AlertTimerState = false;
      if (menunumber == 0) PrintBPMBar();
    }
  }
}

void ScreenOnTimer() {  // automatically dim or turn OFF display

  static unsigned long SampleTime = 0;  // time at which the timer was set
  static bool TimerState = false;       // is the timer still running?

  if (StartScreenTimer) {  // start the timer
    StartScreenTimer = false;
    TimerState = true;
    SampleTime = millis();
    oled.sendCommand(OLED_DISPLAY_ON);
    oled.setContrast(255);
  }

  if (TimerState && millis() - SampleTime > 4000) {  // if the timer is running, check if it has expired
    TimerState = false;

    if (menunumber == 0 && !recording && !playing && internalClock) {  // check if the screen should be turned off or dimmed
      oled.sendCommand(OLED_DISPLAY_OFF);
    } else {
      oled.setContrast(1);
    }
  }
}

void SynthReset() {  // clear note caches

  for (uint8_t i = 0; i < QUEUE_LENGTH; i++) {  // clear note queue
    cronNote[i] = -1;
    cronLength[i] = -1;
  }

  ClearArpBuffer();
  AllNotesOff();
}

void ClearArpBuffer() {  // clear arpeggiator buffer

  numActiveNotes = 0;
  for (uint8_t i = 0; i < MAX_ARPNOTES; i++) {  // clear the activeNotes buffer
    activeNotes[i] = 0;
  }
  countStep = -1;  // rewind step count
  ArpDirection = true;
  arpcount = 0;  // not sure if needed
}

void AllNotesOff() {  // send allnoteoff control change

  SendCC(123, 0, midiChannel);
}

void ConnectPort(uint8_t portselect) {  // connects sync ports

  if (portselect == 1) {
    MIDI.setHandleClock(HandleExternalClock);
    MIDI.setHandleStart(HandleStart);
    MIDI.setHandleStop(HandleStop);
    MIDI.setHandleContinue(HandleContinue);
  } else if (portselect == 2) {
    MIDI2.setHandleClock(HandleExternalClock);
    MIDI2.setHandleStart(HandleStart);
    MIDI2.setHandleStop(HandleStop);
    MIDI2.setHandleContinue(HandleContinue);
  }
}

void DisconnectPort(uint8_t portselect) {  // disconnects sync ports

  if (portselect == 1) {
    MIDI.disconnectCallbackFromType(midi::Clock);
    MIDI.disconnectCallbackFromType(midi::Start);
    MIDI.disconnectCallbackFromType(midi::Stop);
    MIDI.disconnectCallbackFromType(midi::Continue);
  } else if (portselect == 2) {
    MIDI2.disconnectCallbackFromType(midi::Clock);
    MIDI2.disconnectCallbackFromType(midi::Start);
    MIDI2.disconnectCallbackFromType(midi::Stop);
    MIDI2.disconnectCallbackFromType(midi::Continue);
  }
}

void SetSyncPort(uint8_t port) {  // set port for external sync, 0: no port, 1: port1, 2: port2

  for (uint8_t i = 1; i <= 3; i++) {
    if (i == port) ConnectPort(i);
    else DisconnectPort(i);
  }
}

void ScreenBlink() {  // blinks screen

  oled.sendCommand(OLED_DISPLAY_OFF);
  oled.sendCommand(OLED_DISPLAY_ON);
  confirmsound = true;
}

void PrintTitle() {  // title printing setup

  oled.setSize(2);
  oled.invertText(true);
}

void PrintBottomText() {  // bottom small text printing setup

  oled.setSize(2);
  oled.setCursorXY(0, 48);
}

void Bip(uint8_t type) {  // bip sounds

  if (soundmode == 3) return;  // all sounds off

  if (type == 1) {  // click
    if (soundmode == 1) tone8.tone(3136, 1);
  } else if (type == 2) {  // startup/confirmation
    if (soundmode == 1) tone8.tone(2637, 10);
  }

  else if (type == 3) tone8.tone(3136, 5);  // metronome
  else if (type == 4) tone8.tone(2349, 5);  // metronome
}
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

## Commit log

2024-12-12 Fixed tempo indicator behavior
    [Arpmini.ino]
2024-12-12 Update Arpmini.ino
    To avoid redundancy with the term "mode" the "arpeggio modes" have now been renamed to "arpeggio styles".
    [Arpmini.ino]
2025-01-01 Update Arpmini_plus.ino
    Enabled commands for multiple button combinations when controlling the device remotely
2025-01-05 Update 1.98
    - Code optimization
    - Improved sustain pedal management
    - Extended tempo range from 50-250 BPM to 20-250 BPM
    - Implemented internal recording of an arpeggio (in Arp Mode) directly to a chosen sequence track
    - Added the possibility to choose which sequence to begin recording on, directly from the main screen
2025-01-11 Update 2.01
    - Pitch and scale transpositions can be managed separately
    - Pitch, scale, and other related settings are saved and loaded with each song.
2025-01-30 Update 2.07
    - Implemented a 'jitter' parameter to introduce random variations, paving the way for generative music!
    - Small optimizations
    [Arpmini_plus.ino]
2025-02-19 Update GyverOLED.h
    - Added print and println from PROGMEM functions
2025-03-24 Update 2.12
    Corrected some errors in the code
    [Arpmini_plus.ino]
2025-05-06 Update 2.14
    - Added polyphonic drum sequencer capabilities (8 voices max)
    + Recording while playing
    + Beat editor interface (piano roll)
    + Custom MIDI-Note mapping for each "drum note"
    - Added proper "Continue" MIDI message handeler
    - Expanded save slot from 6 to 60 (only for external eeprom)
    + Custom I2C eeprom driver
    + Redesigned file manager
    - Added Key-combo for resetting eeprom at startup (for first-time-run or in case of a problem)
    - Huge code optimization
    + Custom 8 bit random numbers generator
    + Custom SPI oled driver
    - Bug fixes
    - QoL improvements
    [Arpmini_plus.ino]
2025-05-12 Update 2.15
    Custom speaker driver
2025-05-12 Update 2.15
    - Added polyphonic by-step-recording for drum tracks
    + add or remove multiple notes independently
    - Expanded by-step-recording's controls
    + green button -> go to the next step
    + blue button -> clear current step
    + green + blue button -> go back to the previous step
    - Small changes and bug-fixes
    +smaller and more efficient custom speaker driver
    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
    [Arpmini_plus.ino]
2025-05-12 Update 2.16
    Small changes and error corrections
    [Arpmini_plus.ino]
2025-05-13 Update 2.17
    Fixed on-board LED initialization
    [Arpmini_plus.ino]
2025-05-14 Update 2.18
    - Implemented arbitrary starting point for pattern chaining
    - Implemented key combo to resume playback before stop
    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
    [Arpmini_plus.ino]
2025-05-19 Update 2.19
    Bug fixes
    [SPI_OLED.h]
2025-06-10 Enclosure 3D model
    [Arpmini 1.65 v3.stl]
2025-06-12 Update 2.20
    - Increased the number of available sequences from 4 to 8
    - Updated the Live mode layout to handle 8 sequences instead of 4
    - Fixed an issue that could cause unwanted noise in the speaker
    - Improved performance of saving and loading songs
    - Bugfixes
    - Various optimizations
    [Arpmini_plus.ino]
2025-06-14 Update 2.21
    - Added new "Phrygian" scale
    - UI improvements
    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
    [Arpmini_plus.ino]
2025-07-10 Arpmini Update 2.22
    -Renamed project from "Arpmini Plus" to "Arpmini"
    -Separated external EEPROM class to avoid redundancy
    -Restored EEPROM auto-reset on first boot
    -Reorganized EEPROM usage
    -Improved reboot (reset) function
    -Added 3 new playback speeds (1/24, 1/6, 1/4)
    -Added startup animation
    -Implemented song import/export system (via Arpmini Editor)
    -Improved tap tempo accuracy
    [Arpmini.ino]
2025-07-29 Rename Arpmini 1.65 v3.stl to extras/Arpmini 1.65 v3.stl
    [Arpmini 1.65 v3.stl]
2025-08-05 Update 2.23
    - added new menu voice “keyboard control”
    to manage various keyboard interaction methods
    - added “strum” functionality to the arpeggiator
    - enable/disable by-keyboard transposition
    - added “drum roll” functionality in drum mode
    - added “mixer mode” to mute/unmute individual drum slots
    - better handling for note lengths
    - improved multitasking: reduced delays during eeprom reads/writes and screen updates (work in progress. may cause some graphical glitches)
    - various improvements and bug fixes
    [Arpmini.ino]
2025-08-07 Update 2.24
    - bugfixes
    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
    [Arpmini.ino]
2025-08-07 Update 2.24
    implemented rudimentary function for printing white rectangles
2025-08-13 Update 2.26
    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
    [Arpmini.ino]
2025-08-19 Update 2.27
    - New and improved notification system: less intrusive, auto-dismissing notifications. Added more alerts and contextual feedback across the system.
    - Step sequencer enhancements: added backward circularity and new notifications to improve the recording workflow.
    - Beat editor improvements: each drum slot can now be selected and enabled/disabled directly in the editor. Redesigned sequence-changing behavior to reduce accidental selections.
    - UI refinements and bug fixes
    [Arpmini.ino]
2025-08-22 Update 2.28
    bug fix
    [Arpmini.ino]
2025-10-21 Update 2.3
    - added a new tool for interactive editing and composition of melodic lines in MIDI tracker style, the “Note Editor” (a complementary tool to the existing “Beat Editor”)
    - improved user experience in the “Beat Editor”
    - unified key combination functions between Rec and Song modes
    - simplified initialization and improved speaker driver performance
    - new memory reset screen
    - expanded EEPROM management with a new, larger song format to include additional parameters
    - simplified and more efficient data exchange handling with "Arpmini Editor" for PC & Mac
    - reorganized timing management for greater efficiency and accuracy
    - improved arpeggio algorithms and enhanced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
    [Arpmini.ino]
2025-11-11 Update 2.32
    -Added USB MIDI support
    -Small optimizations and fixes
    [Arpmini.ino]
2026-06-14 Update 2.34
    -enable/disable note directly in by-step recording (not in drum mode)
    -simpler mixer control (toggle instead of switch)
    -added tap tempo indicator
2026-07-01 Update 2.3.5
    - implemented count-off (countdown before recording)
    - implemented key-combination to clear a sequence
    - bug fixes and optimizations
    [Arpmini.ino]
2026-07-30 Update 2.36
    - implemented a delayed start-realtime-message after the count-off
    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
    [Arpmini.ino]
2026-09-11 Update 2.37
    fixed a feasture's name ambiguity
    [Arpmini.ino]

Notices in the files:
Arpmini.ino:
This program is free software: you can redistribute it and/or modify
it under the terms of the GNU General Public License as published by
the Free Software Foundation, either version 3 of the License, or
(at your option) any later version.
